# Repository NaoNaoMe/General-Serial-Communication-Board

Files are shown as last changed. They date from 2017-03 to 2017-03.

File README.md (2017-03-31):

General Serial Communication Board
=========

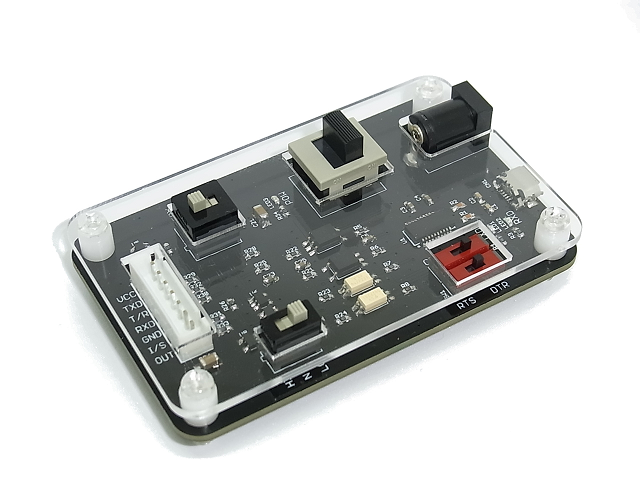
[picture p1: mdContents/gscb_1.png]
General Serial Communication Board
  
The General Serial Communication Board is an USB to Serial converter with FTDI Chipset.  
Full/Half-duplex UART, DTR/RTS signals, and 3-position will be adapted microcontroller you may use.  
These features are useful for serial flash programming.  
This board also has opto-isolaters to prevent electrical shock, get rid of Ground Loop track and protect your computer.  

### Some highlights of the General Serial Communication Board:
 1. USB UART Bridge: FTDI FT231X Based on the popular FTDI FT231X converter
 2. UART interface circuit accepts 3.3V and 5.0V.
 3. Electrical isolation between UART interface and USB interface.
 4. All standard serial data rates and up to 3Mega baud.
 5. Full duplex mode and Half duplex mode are selectable(SW4).
 6. Flow control pins are avilable (DTR or RTS, SW1) and (DSR or CTS, SW2)
 7. 3-state user switch(SW3) connected to ftdi is selectable VCC, weak pulldown or GND.
 8. Measures 40mm x 80mm x 20mm

Repository Contents
-------------------
* **/Mechanical** - Mechanical data files (.dxf, .dwg)
* **/Hardware** - All Eagle design files (.brd, .sch)

Description(Pin Interfaces)
-------------------
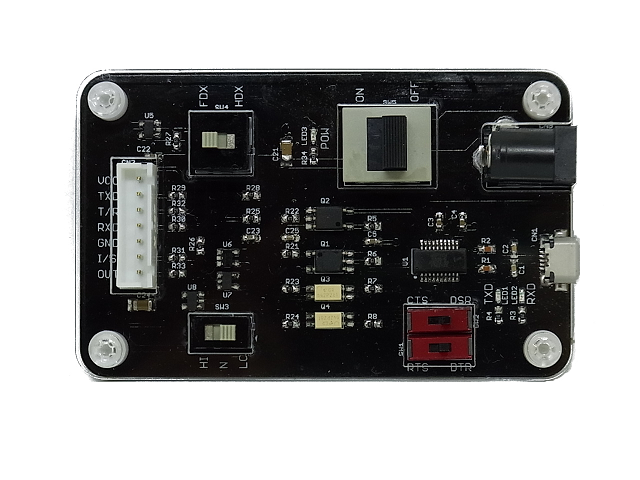
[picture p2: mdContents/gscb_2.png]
TopView


### CN1(Primarily) Connector Descriptions:
Micro B-type usb connector

### CN2(Secondary) Connector Descriptions:
Barrel Power Jack socket
This socket is connected to VIN pin on CN3 with the main power switch(SW5).  
The power supply must follow microcontroller requirements.

### CN3(Secondary) Pin Descriptions:
This connector is for your target boart.
- **VIN:** UART interface power supply with a voltage range of 2.7 to 5.5VDC.
- **TX:** Full duplex TX signal(CMOS TTL output).
- **TX/RX:** Half duplex signals(Open collector output).
- **RX:** Full duplex RX signal.
- **GND:** GND.
- **I/S:** User switch (Active High signal) and input to DSR or CTS.
- **OUT:** DTR or RTS signal (Active High signal).

License Information
-------------------
The repository is released under [Creative Commons ShareAlike 4.0 International](https://creativecommons.org/licenses/by-sa/4.0/).

Distributed as-is; no warranty is given.

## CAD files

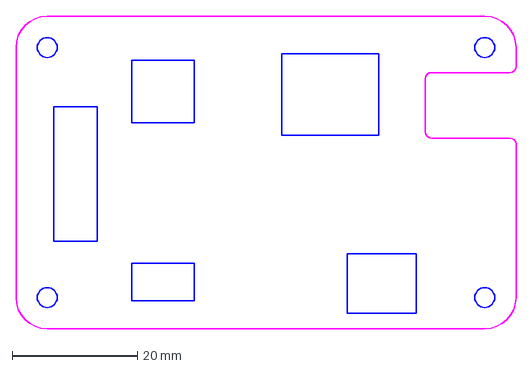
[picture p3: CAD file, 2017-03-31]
Mechanical/Cover/GeneralSerialCommBoard.dxf
80.0 x 50.0 mm

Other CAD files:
Mechanical/Cover/GeneralSerialCommBoard.dwg

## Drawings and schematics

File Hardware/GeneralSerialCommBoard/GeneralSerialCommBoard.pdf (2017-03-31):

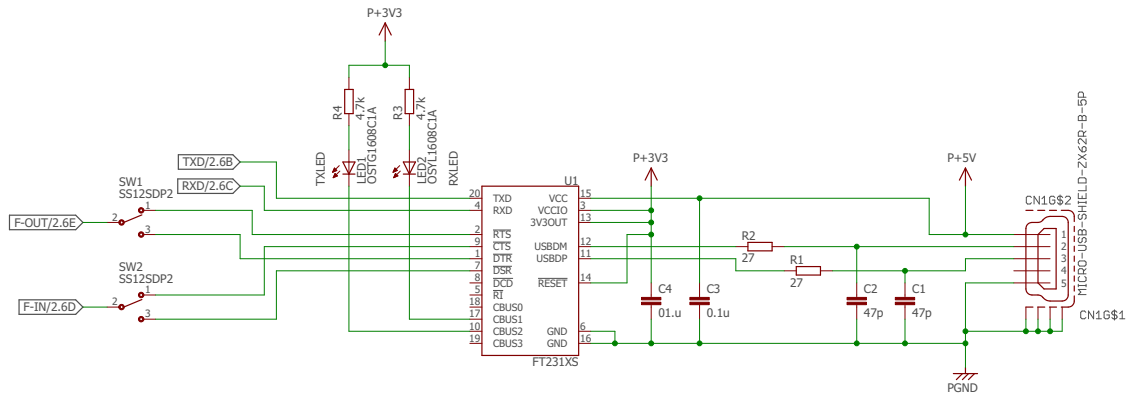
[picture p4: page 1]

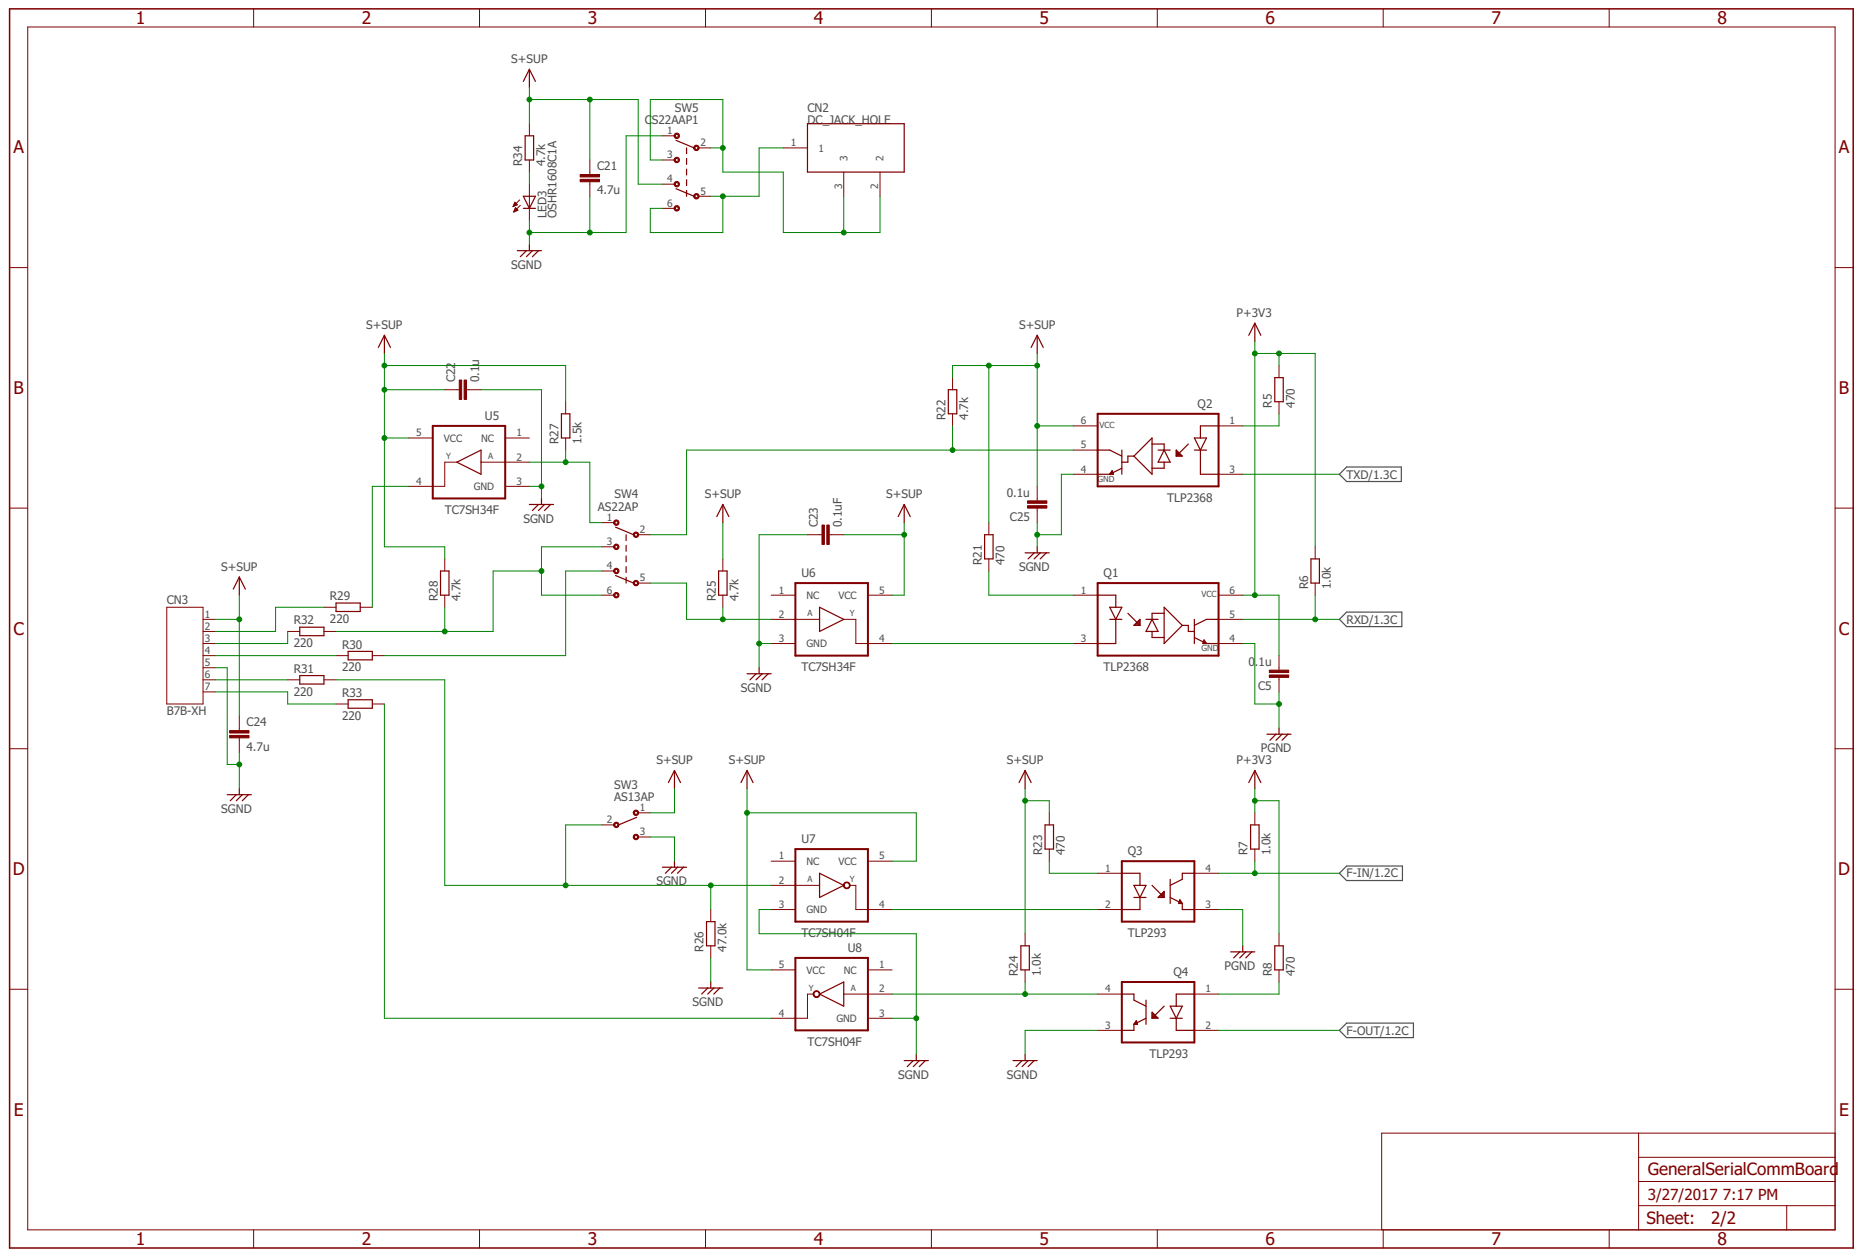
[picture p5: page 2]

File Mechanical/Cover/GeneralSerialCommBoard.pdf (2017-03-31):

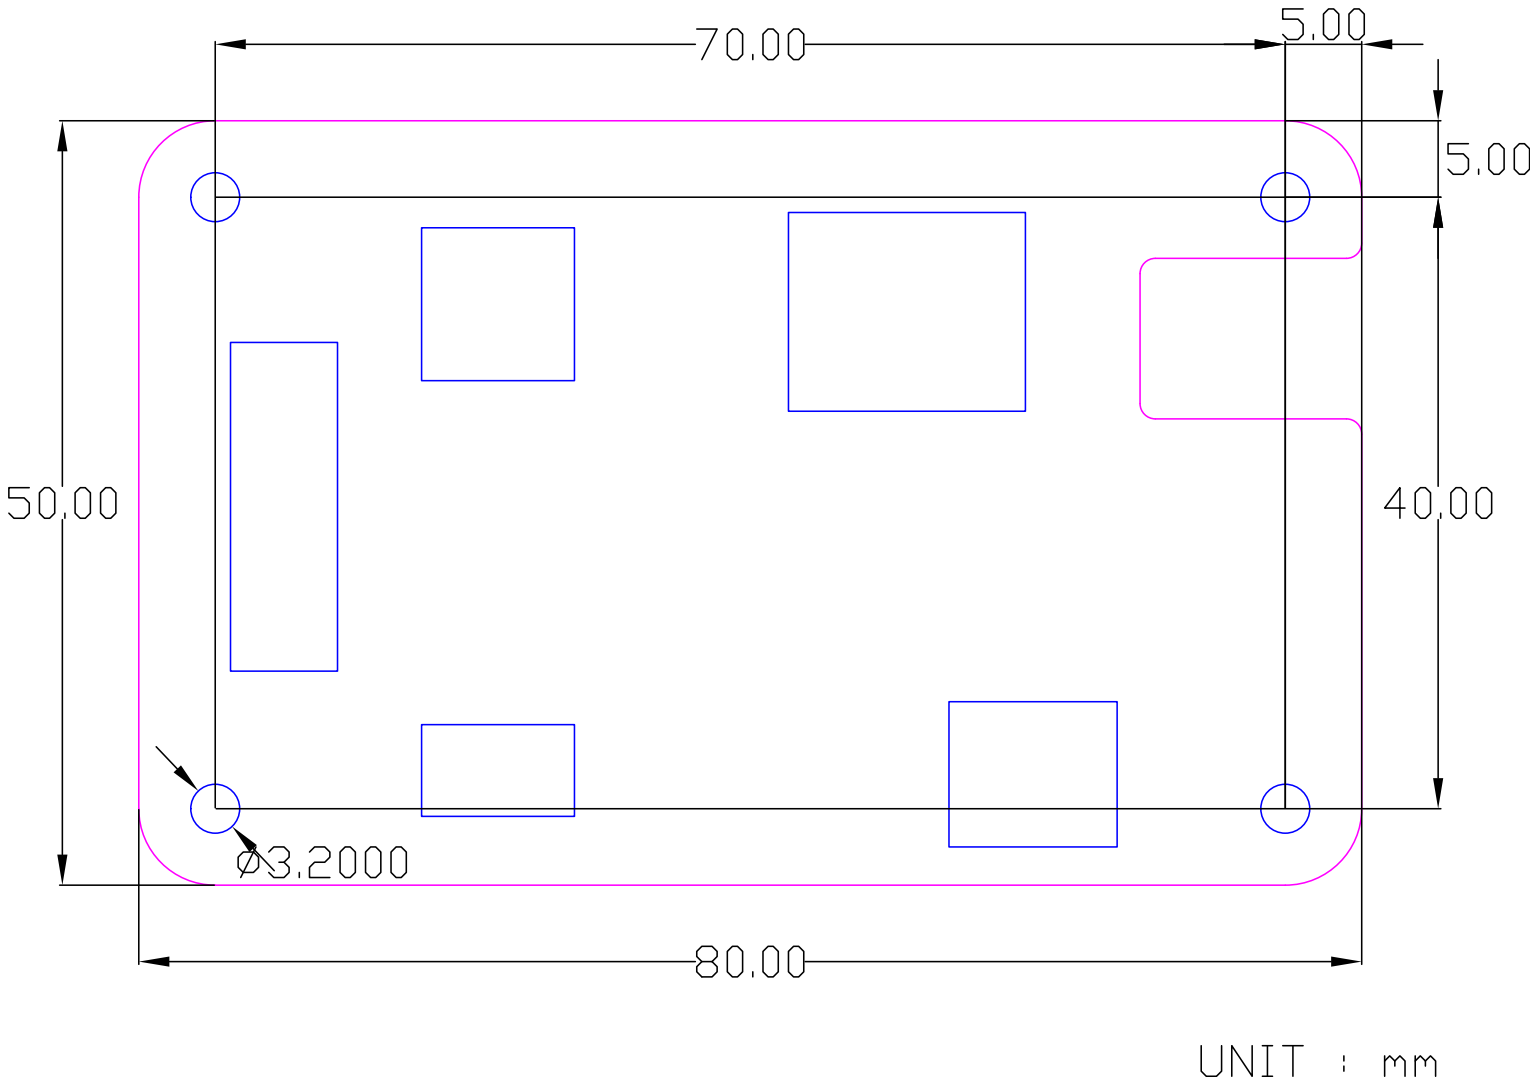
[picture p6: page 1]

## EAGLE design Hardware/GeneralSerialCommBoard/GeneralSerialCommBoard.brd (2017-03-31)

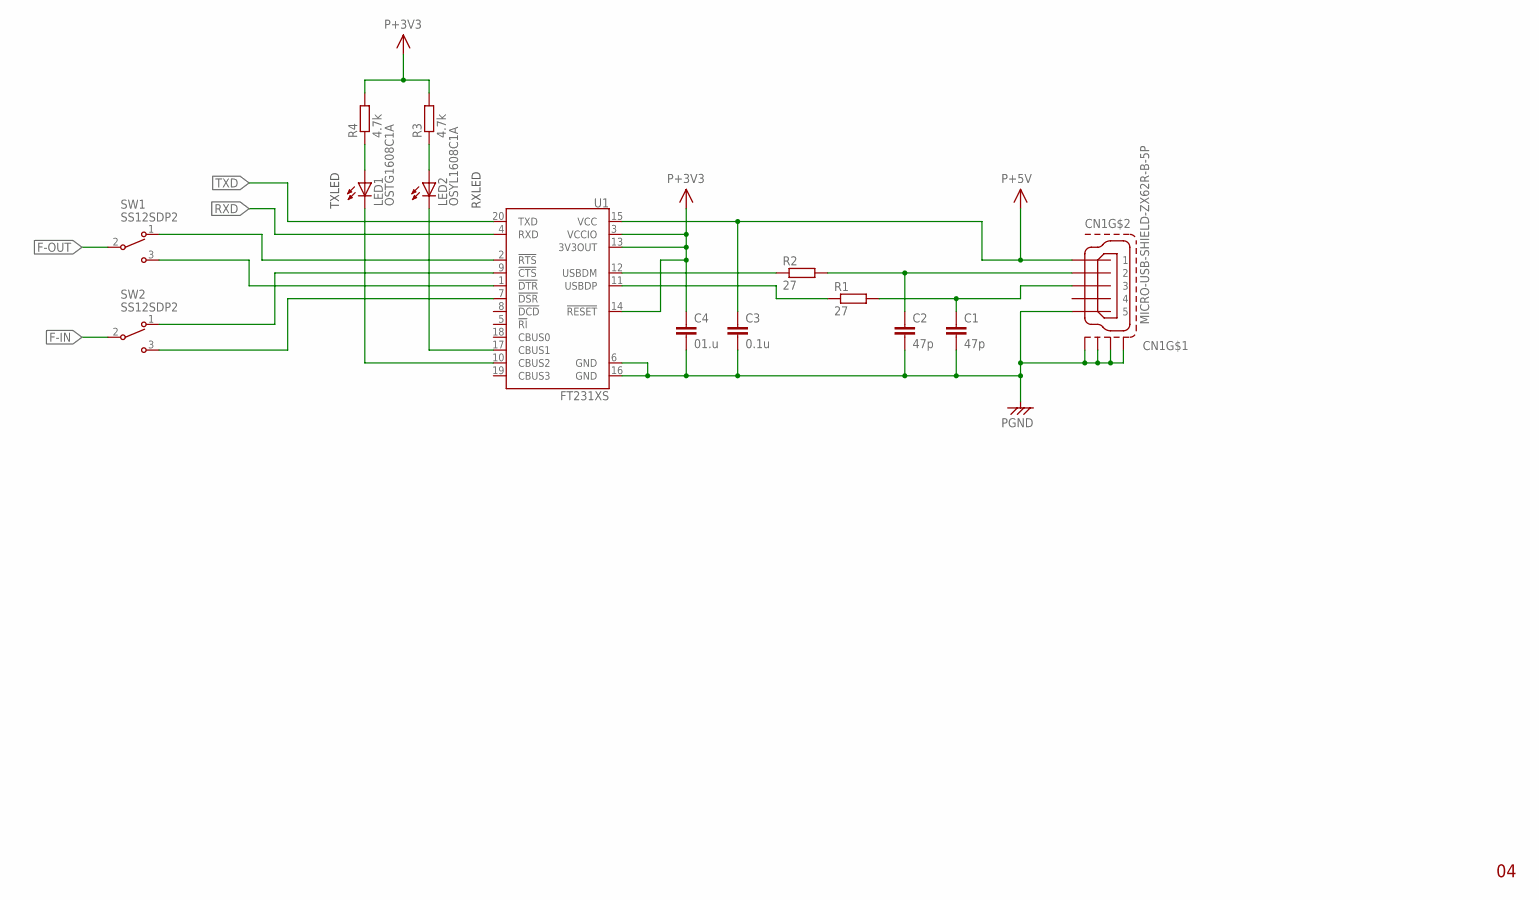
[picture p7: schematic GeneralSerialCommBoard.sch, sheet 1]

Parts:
C1, C2: 47p; C0603
C3: 0.1u; C0603
C4: 01.u; C0603
CN1: MICRO-USB-SHIELD-ZX62R-B-5P; ZX62R-B-5P
LED1: OSTG1608C1A; 1608SMD
LED2: OSYL1608C1A; 1608SMD
R1, R2: 27; R0603
R3, R4: 4.7k; R0603
SW1, SW2: SS12SDP2
U1: FT231XS; SSOP20_L

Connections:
CBUS1: LED2.K (C), U1.17 (CBUS1)
CBUS2: LED1.K (C), U1.10 (CBUS2)
CTS: SW2.1 (T1), U1.9 (!CTS)
DSR: SW2.3 (T3), U1.7 (!DSR)
DTR: SW1.3 (T3), U1.1 (!DTR)
F-IN: SW2.2 (COM2); also elsewhere on the board
F-OUT: SW1.2 (COM2); also elsewhere on the board
unnamed: C1.1, CN1.3, R1.2
unnamed: C2.1, CN1.2, R2.2
unnamed: LED2.A, R3.1
unnamed: LED1.A, R4.1
unnamed: R2.1, U1.12 (USBDM)
unnamed: R1.1, U1.11 (USBDP)
P+3V3: C4.1, R3.2, R4.2, U1.3 (VCCIO), U1.13 (3V3OUT), U1.14 (!RESET); also elsewhere on the board
P+5V: C3.1, CN1.1, U1.15 (VCC)
PGND: C1.2, C2.2, C3.2, C4.2, CN1.5, CN1.M1 (S1), CN1.M2 (S2), CN1.M3 (S3), CN1.M4 (S4), U1.6 (GND), U1.16 (GND); also elsewhere on the board
RTS: SW1.1 (T1), U1.2 (!RTS)
RXD: U1.4 (RXD); also elsewhere on the board
TXD: U1.20 (TXD); also elsewhere on the board

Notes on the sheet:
TXLED
RXLED

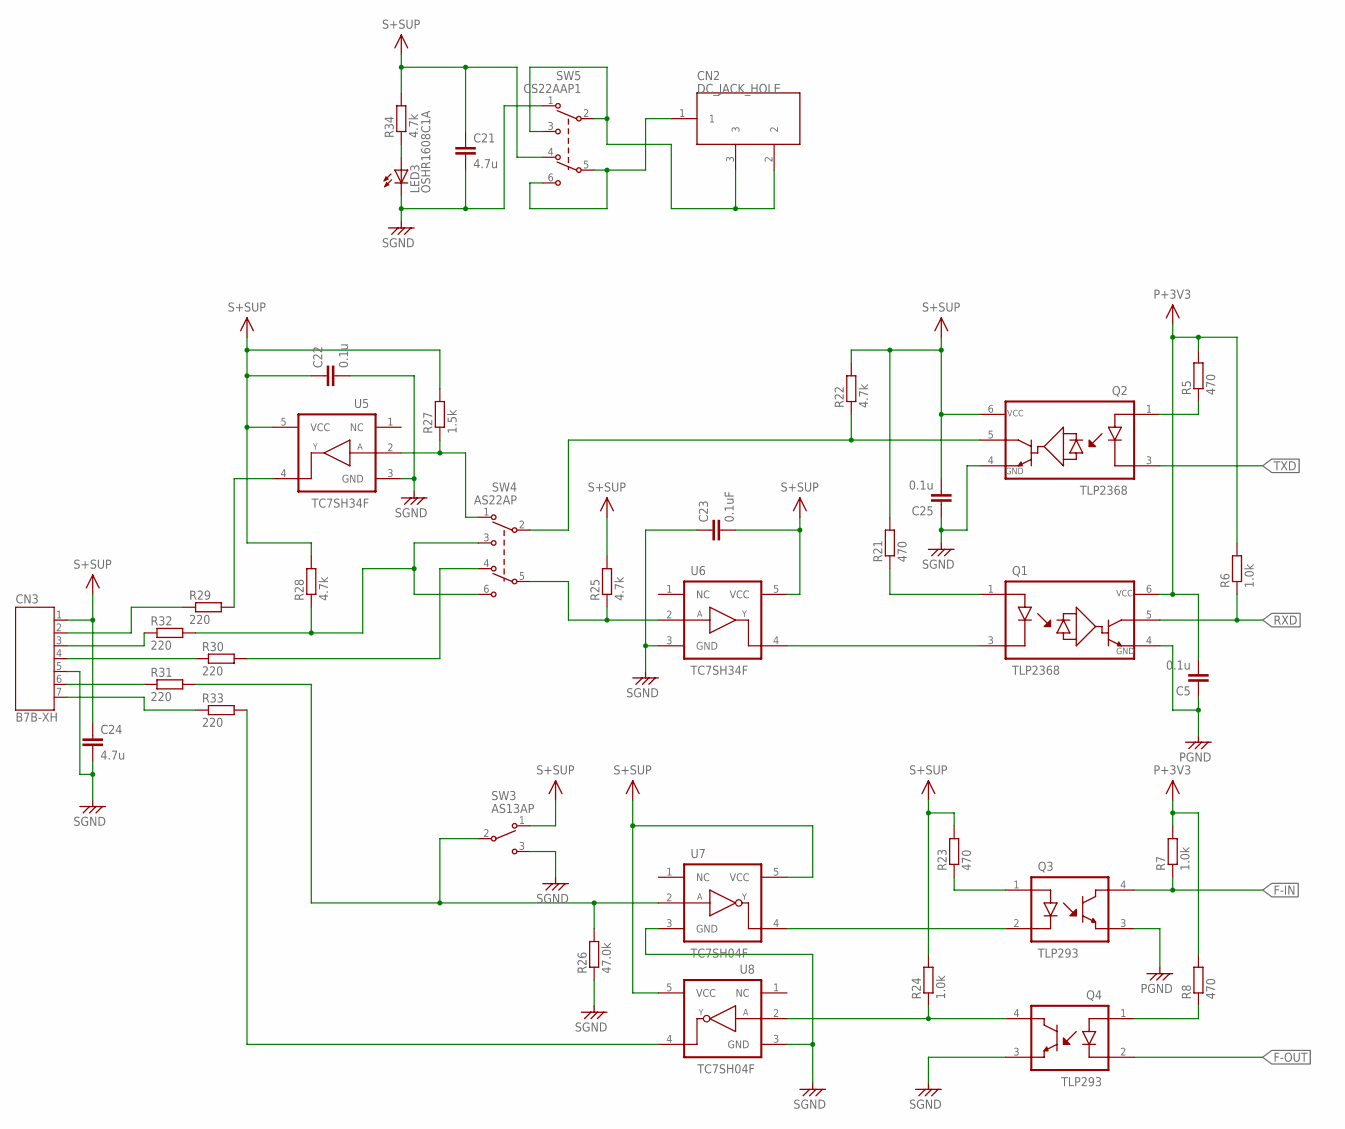
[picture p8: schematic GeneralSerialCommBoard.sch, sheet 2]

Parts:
C5, C22, C25: 0.1u; C0603
C21, C24: 4.7u; C1206
C23: 0.1uF; C0603
CN2: DC_JACK_HOLE
CN3: B7B-XH
LED3: OSHR1608C1A; 1608SMD
Q1, Q2: TLP2368; SO6-5PIN
Q3, Q4: TLP293; SO4
R5, R8, R21, R23: 470; R0603
R6, R7, R24: 1.0k; R0603
R22, R25, R28, R34: 4.7k; R0603
R26: 47.0k; R0603
R27: 1.5k; R0603
R29, R30, R31, R32, R33: 220; R0603
SW3: AS13AP
SW4: AS22AP
SW5: CS22AAP1
U5, U6: TC7SH34F; SMV
U7, U8: TC7SH04F; SMV

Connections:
F-IN: Q3.4 (C), R7.1; also elsewhere on the board
F-OUT: Q4.2 (K); also elsewhere on the board
unnamed: CN2.1, SW5.5 (COM5), SW5.6 (T6)
unnamed: CN2.2, CN2.3, SW5.2 (COM2), SW5.3 (T3)
unnamed: Q2.1 (A), R5.1
unnamed: Q2.5 (VO), R22.1, SW4.2 (COM2)
unnamed: Q4.1 (A), R8.1
unnamed: CN3.2, R29.1
unnamed: CN3.3, R32.1
unnamed: CN3.4, R30.1
unnamed: CN3.6, R31.1
unnamed: CN3.7, R33.1
unnamed: R29.2, U5.4 (Y)
unnamed: R28.1, R32.2, SW4.3 (T3), SW4.6 (T6)
unnamed: R27.1, SW4.1 (T1), U5.2 (A)
unnamed: Q1.1 (A), R21.1
unnamed: R30.2, SW4.4 (T4)
unnamed: R25.1, SW4.5 (COM5), U6.2 (A)
unnamed: Q1.3 (K), U6.4 (Y)
unnamed: Q3.1 (A), R23.1
unnamed: Q3.2 (K), U7.4 (Y)
unnamed: Q4.4 (C), R24.1, U8.2 (A)
unnamed: R26.2, R31.2, SW3.2 (COM2), U7.2 (A)
unnamed: R33.2, U8.4 (Y)
unnamed: LED3.A, R34.1
P+3V3: C5.2, Q1.6 (VCC), R5.2, R6.2, R7.2, R8.2; also elsewhere on the board
PGND: C5.1, Q1.4 (GND), Q3.3 (E); also elsewhere on the board
RXD: Q1.5 (VO), R6.1; also elsewhere on the board
S+SUP: C21.1, C22.1, C23.2, C24.1, C25.2, CN3.1, Q2.6 (VCC), R21.2, R22.2, R23.2, R24.2, R25.2, R27.2, R28.2, R34.2, SW3.1 (T1), SW5.4 (T4), U5.5 (VCC), U6.5 (VCC), U7.5 (VCC), U8.5 (VCC)
SGND: C21.2, C22.2, C23.1, C24.2, C25.1, CN3.5, LED3.K (C), Q2.4 (GND), Q4.3 (E), R26.1, SW3.3 (T3), SW5.1 (T1), U5.3 (GND), U6.3 (GND), U7.3 (GND), U8.3 (GND)
TXD: Q2.3 (K); also elsewhere on the board

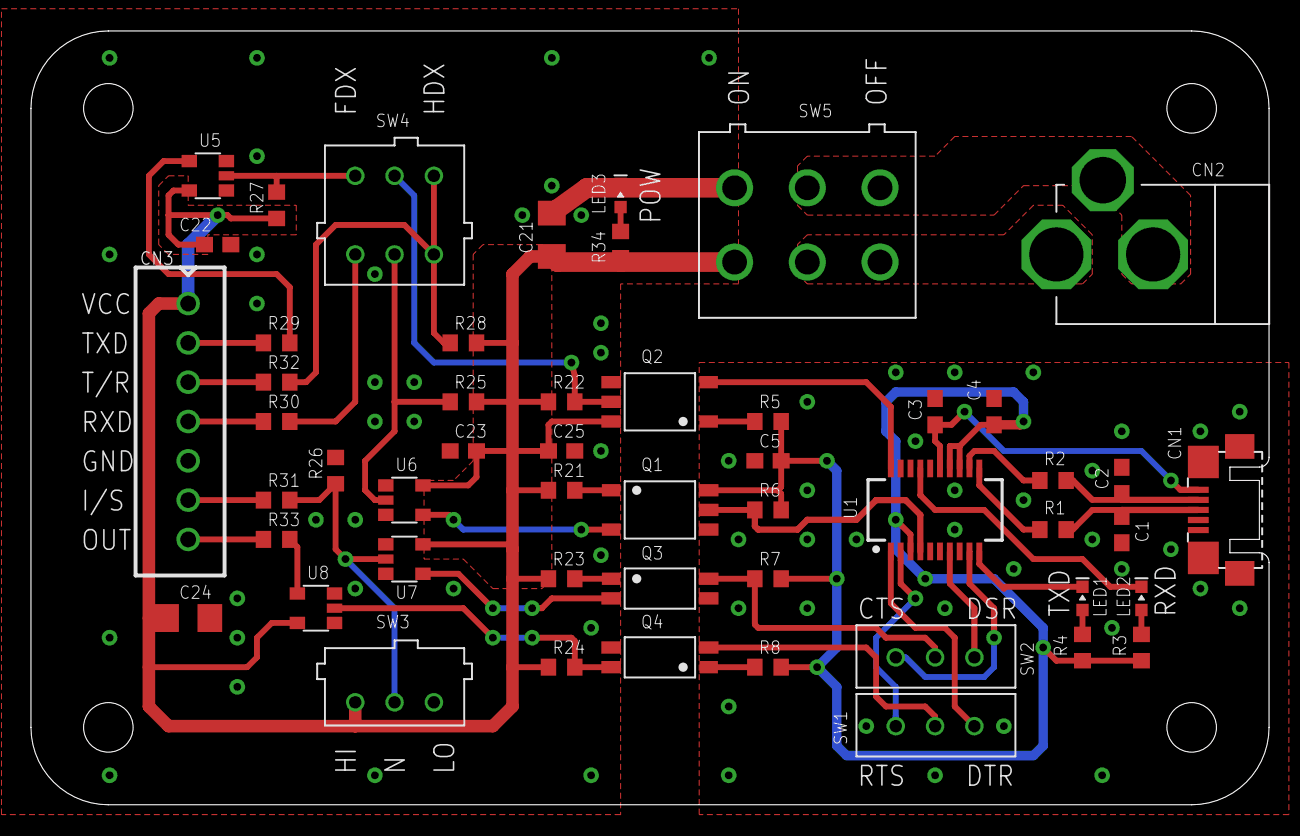
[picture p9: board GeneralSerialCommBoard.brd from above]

Board: 2 copper layers, 80.0 x 50.0 mm, 52 parts (0 on the bottom side), 44 nets.

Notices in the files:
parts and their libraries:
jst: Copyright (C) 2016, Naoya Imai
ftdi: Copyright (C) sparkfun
